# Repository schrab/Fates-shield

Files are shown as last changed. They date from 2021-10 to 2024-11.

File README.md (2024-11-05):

# Fates shield DAC board for Raspberry Pi

Monome [Fates](https://github.com/okyeron/fates) with MIDI and onboard microphone in Monome Shield form-factor

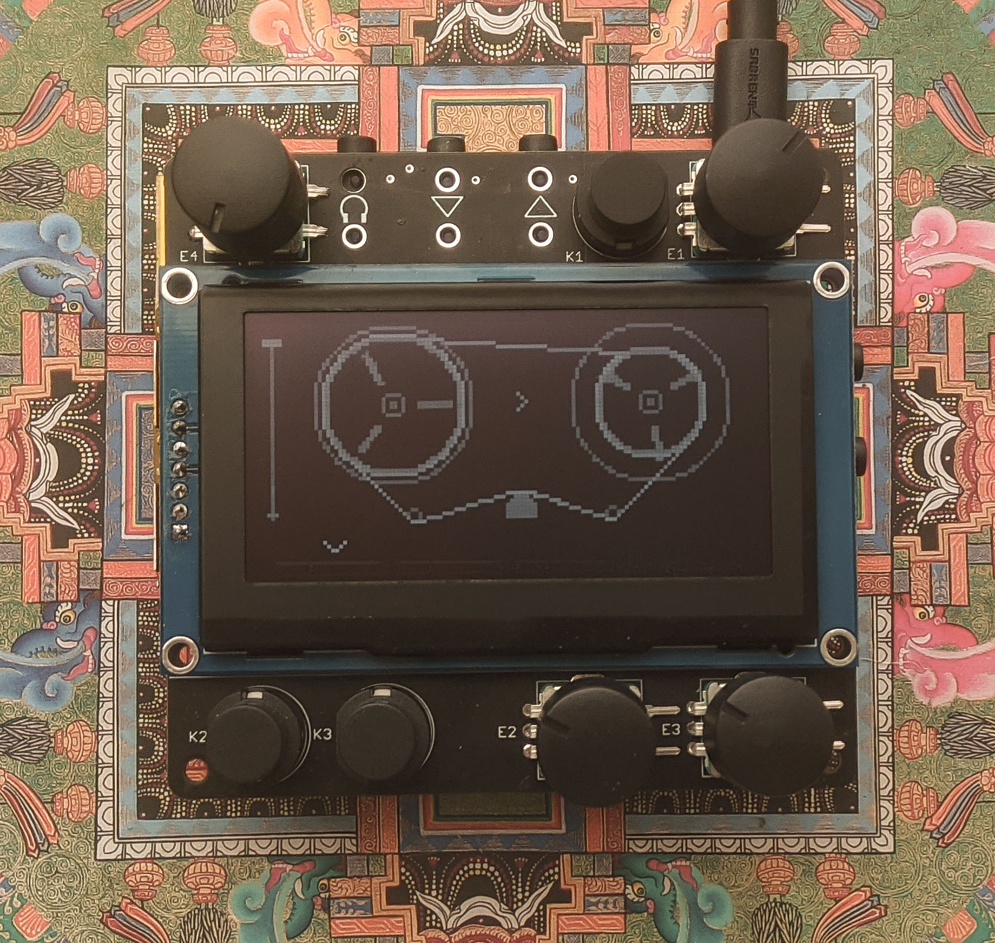
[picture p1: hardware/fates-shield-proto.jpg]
<fates shield>


### Specs:

- WM8731 stereo audio codec with headphone driver
- Microphone
- ZJYM270-7PV2.0 SSD1325 128x64 OLED display (NHD-2.7-12864WDW3 alternative [from Aliexpress](https://aliexpress.ru/item/4000265549668.html))
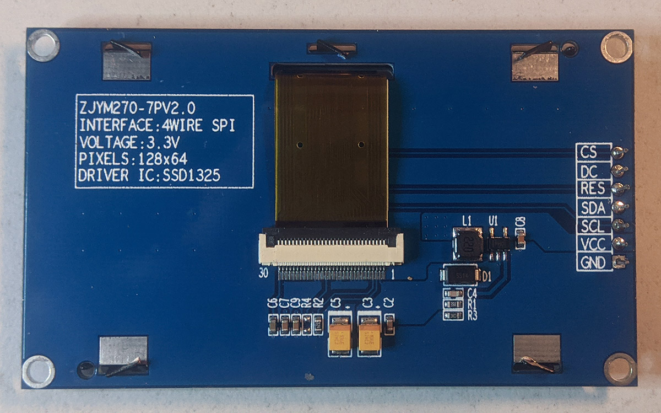
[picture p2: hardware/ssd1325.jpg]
<ssd1325oled>
  
- 3 pushbuttons
- 4 rotary encoders
- 2x 1/8in inputs
- 2x 1/8in outputs
- 1/8in stereo headphone out
- 1/8in UART MIDI in/out

###TODO
  
- [X] Fix upper OLED holes position
- [ ] Add RC filtering for encoders and keys
- [ ] Fix headphone jack hole
- [X] Fix swapped MIDI IN lines
- [X] Fix MIDI OUT buffer lines

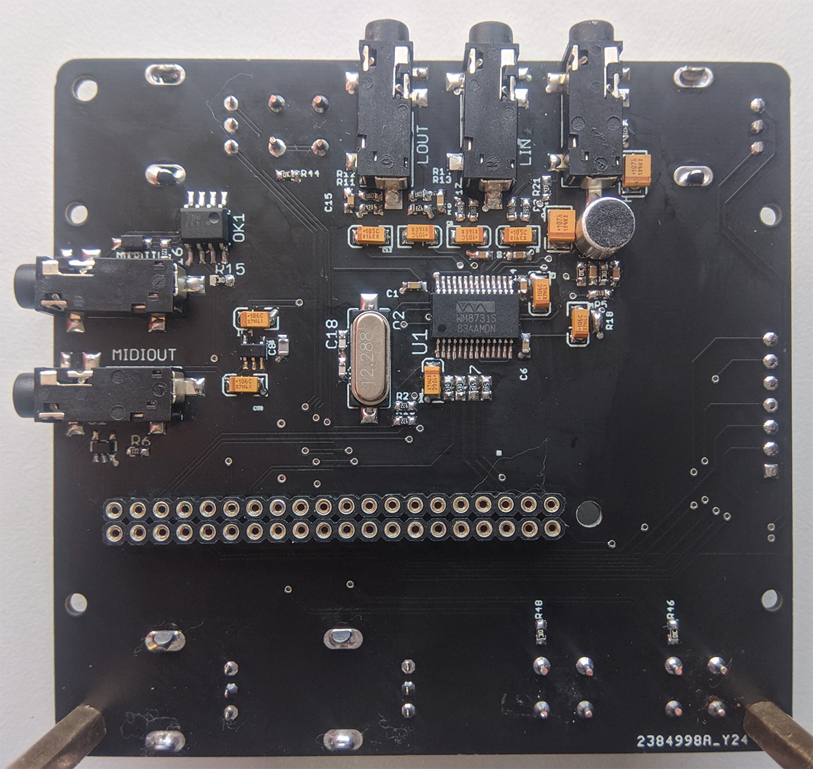
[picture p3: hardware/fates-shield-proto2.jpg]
<fates shield back>


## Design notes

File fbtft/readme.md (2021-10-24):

Dependencies
```sudo apt-get update
sudo apt-get dist-upgrade
sudo apt-get -y install libncurses5-dev
sudo apt-get install git bc raspberrypi-kernel-headers
```

Linux source

    git clone --depth=1 https://github.com/monome/linux
    cd ~/linux
    
Config

    cp /usr/src/linux-headers-$(uname -r)/Module.symvers .
    cp /usr/src/linux-headers-$(uname -r)/.config .

Copy **fb_ssd1325.c** to `~/linux/drivers/staging/fbtft`

Fix Kconfig and Makefile (SSD1305->SSD1325)

    make menuconfig

Select SSD1325

    Device Drivers  ---> Staging Drivers ---> Support for small TFT LCD display modules  --->
    <M>   SSD1325 driver

Compile

    make prepare
    make -j4 -C ~/linux SUBDIRS=drivers/staging/fbtft modules

Move drivers

    sudo cp -v ~/linux/drivers/staging/fbtft/*.ko /lib/modules/$(uname -r)/kernel/drivers/staging/fbtft/
    sudo modep -a

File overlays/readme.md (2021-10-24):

#SSD 1325 Device Tree overlay

SPI frequency set to 32MHz

Copy `fates-shield-ssd1325-overlay.dts` to `/home/we/fates/overlays/`

Compile dtb

    sudo dtc -W no-unit_address_vs_reg -@ -I dts -O dtb -o /boot/overlays/fates-ssd1325.dtbo /home/we/fates/overlays/fates-shield-ssd1325-overlay.dts

Edit `/boot/config.txt`

    # Screen
    dtoverlay=fates-ssd1325

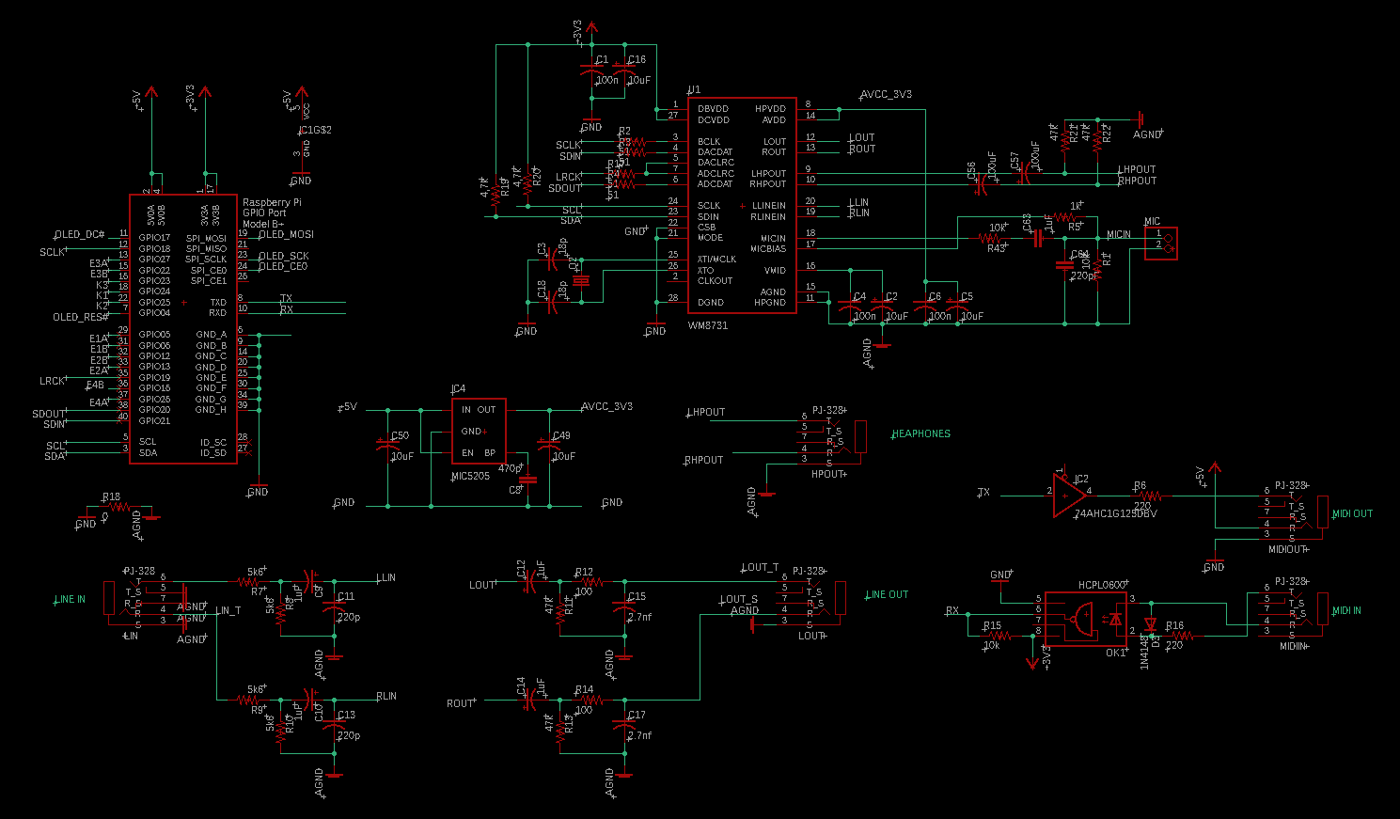
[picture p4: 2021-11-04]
hardware/fates-shield-schematic.png

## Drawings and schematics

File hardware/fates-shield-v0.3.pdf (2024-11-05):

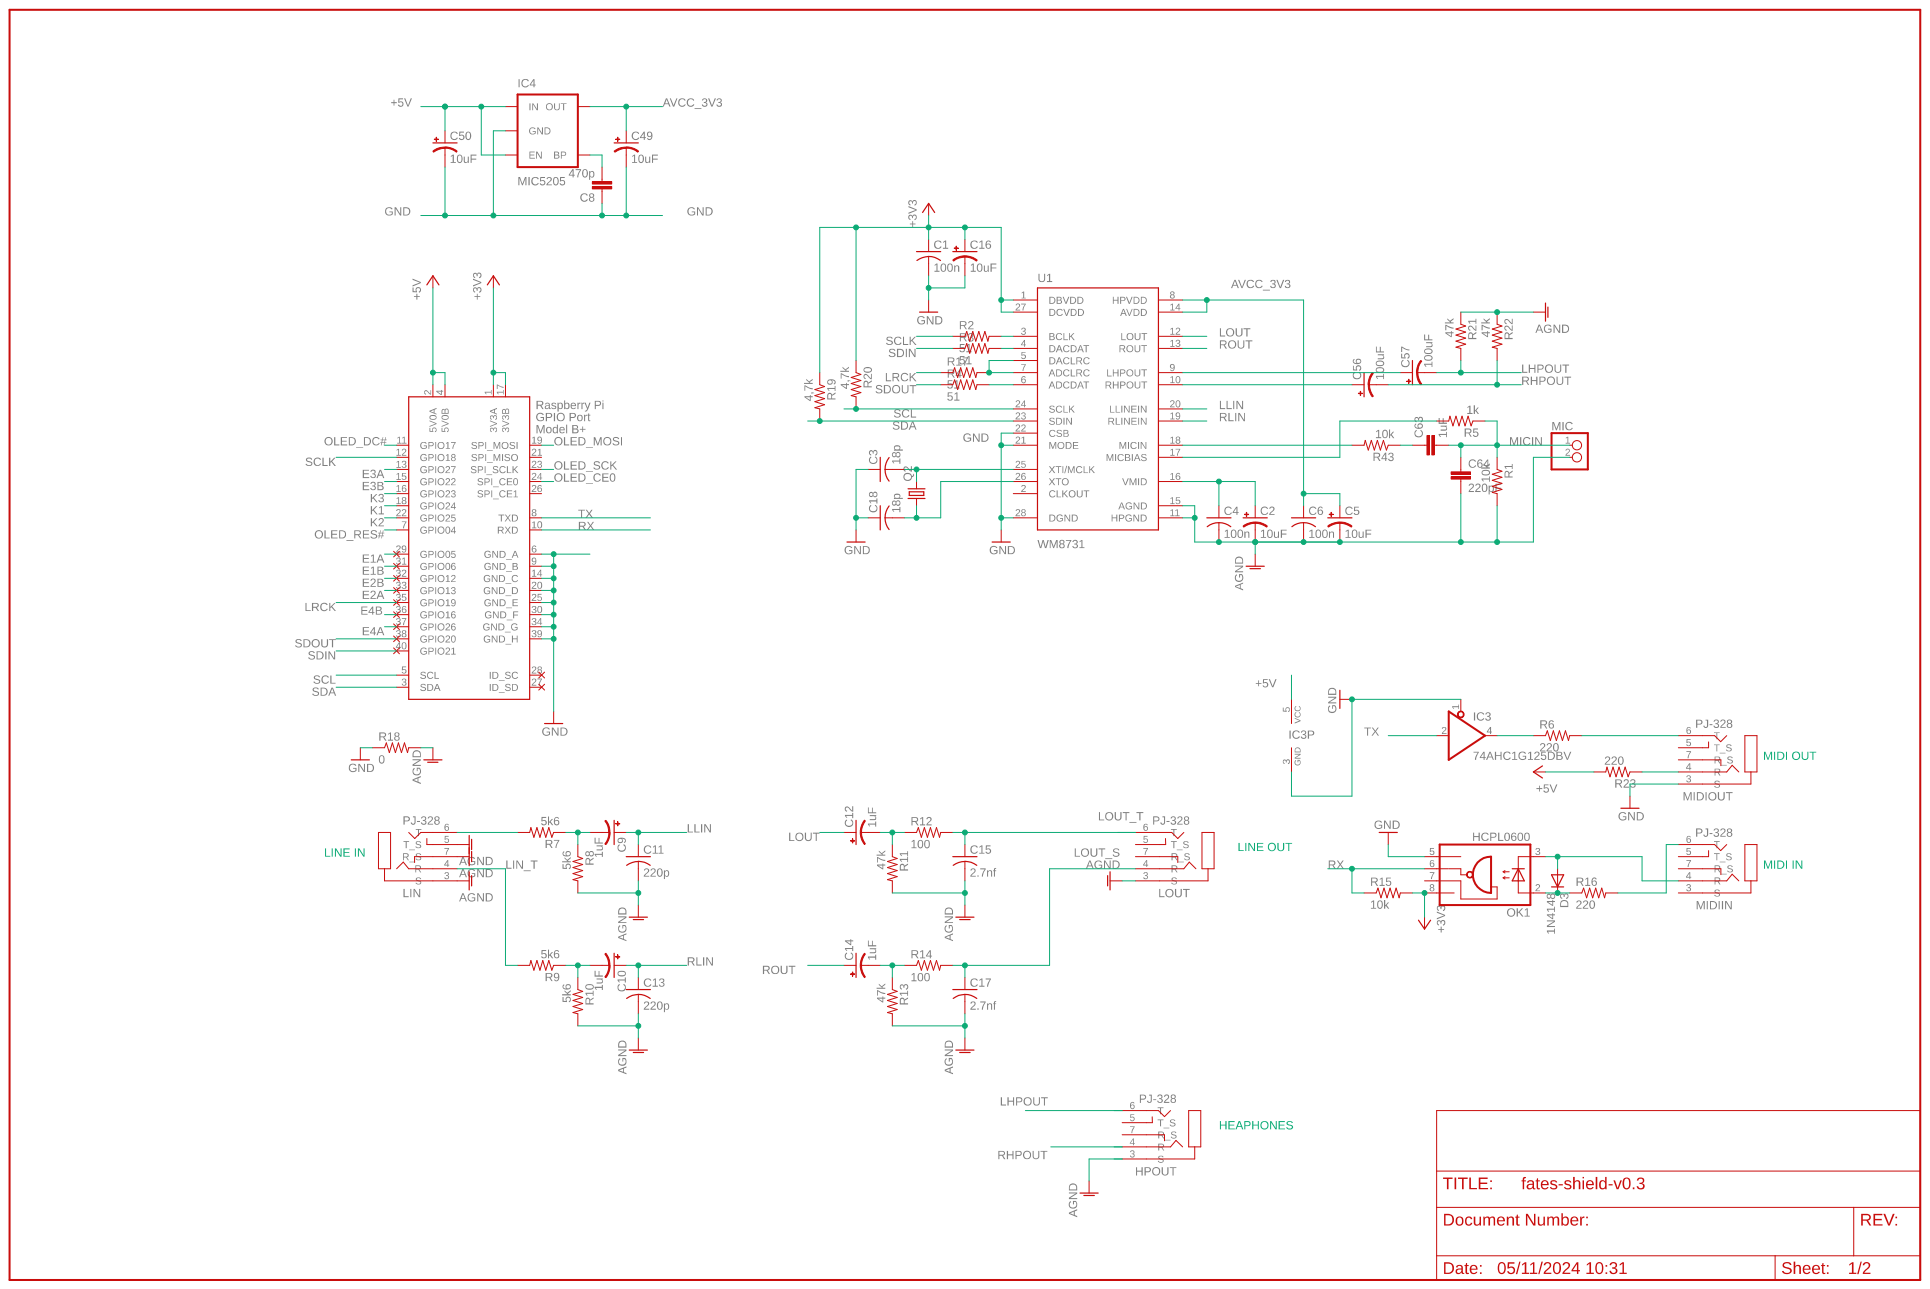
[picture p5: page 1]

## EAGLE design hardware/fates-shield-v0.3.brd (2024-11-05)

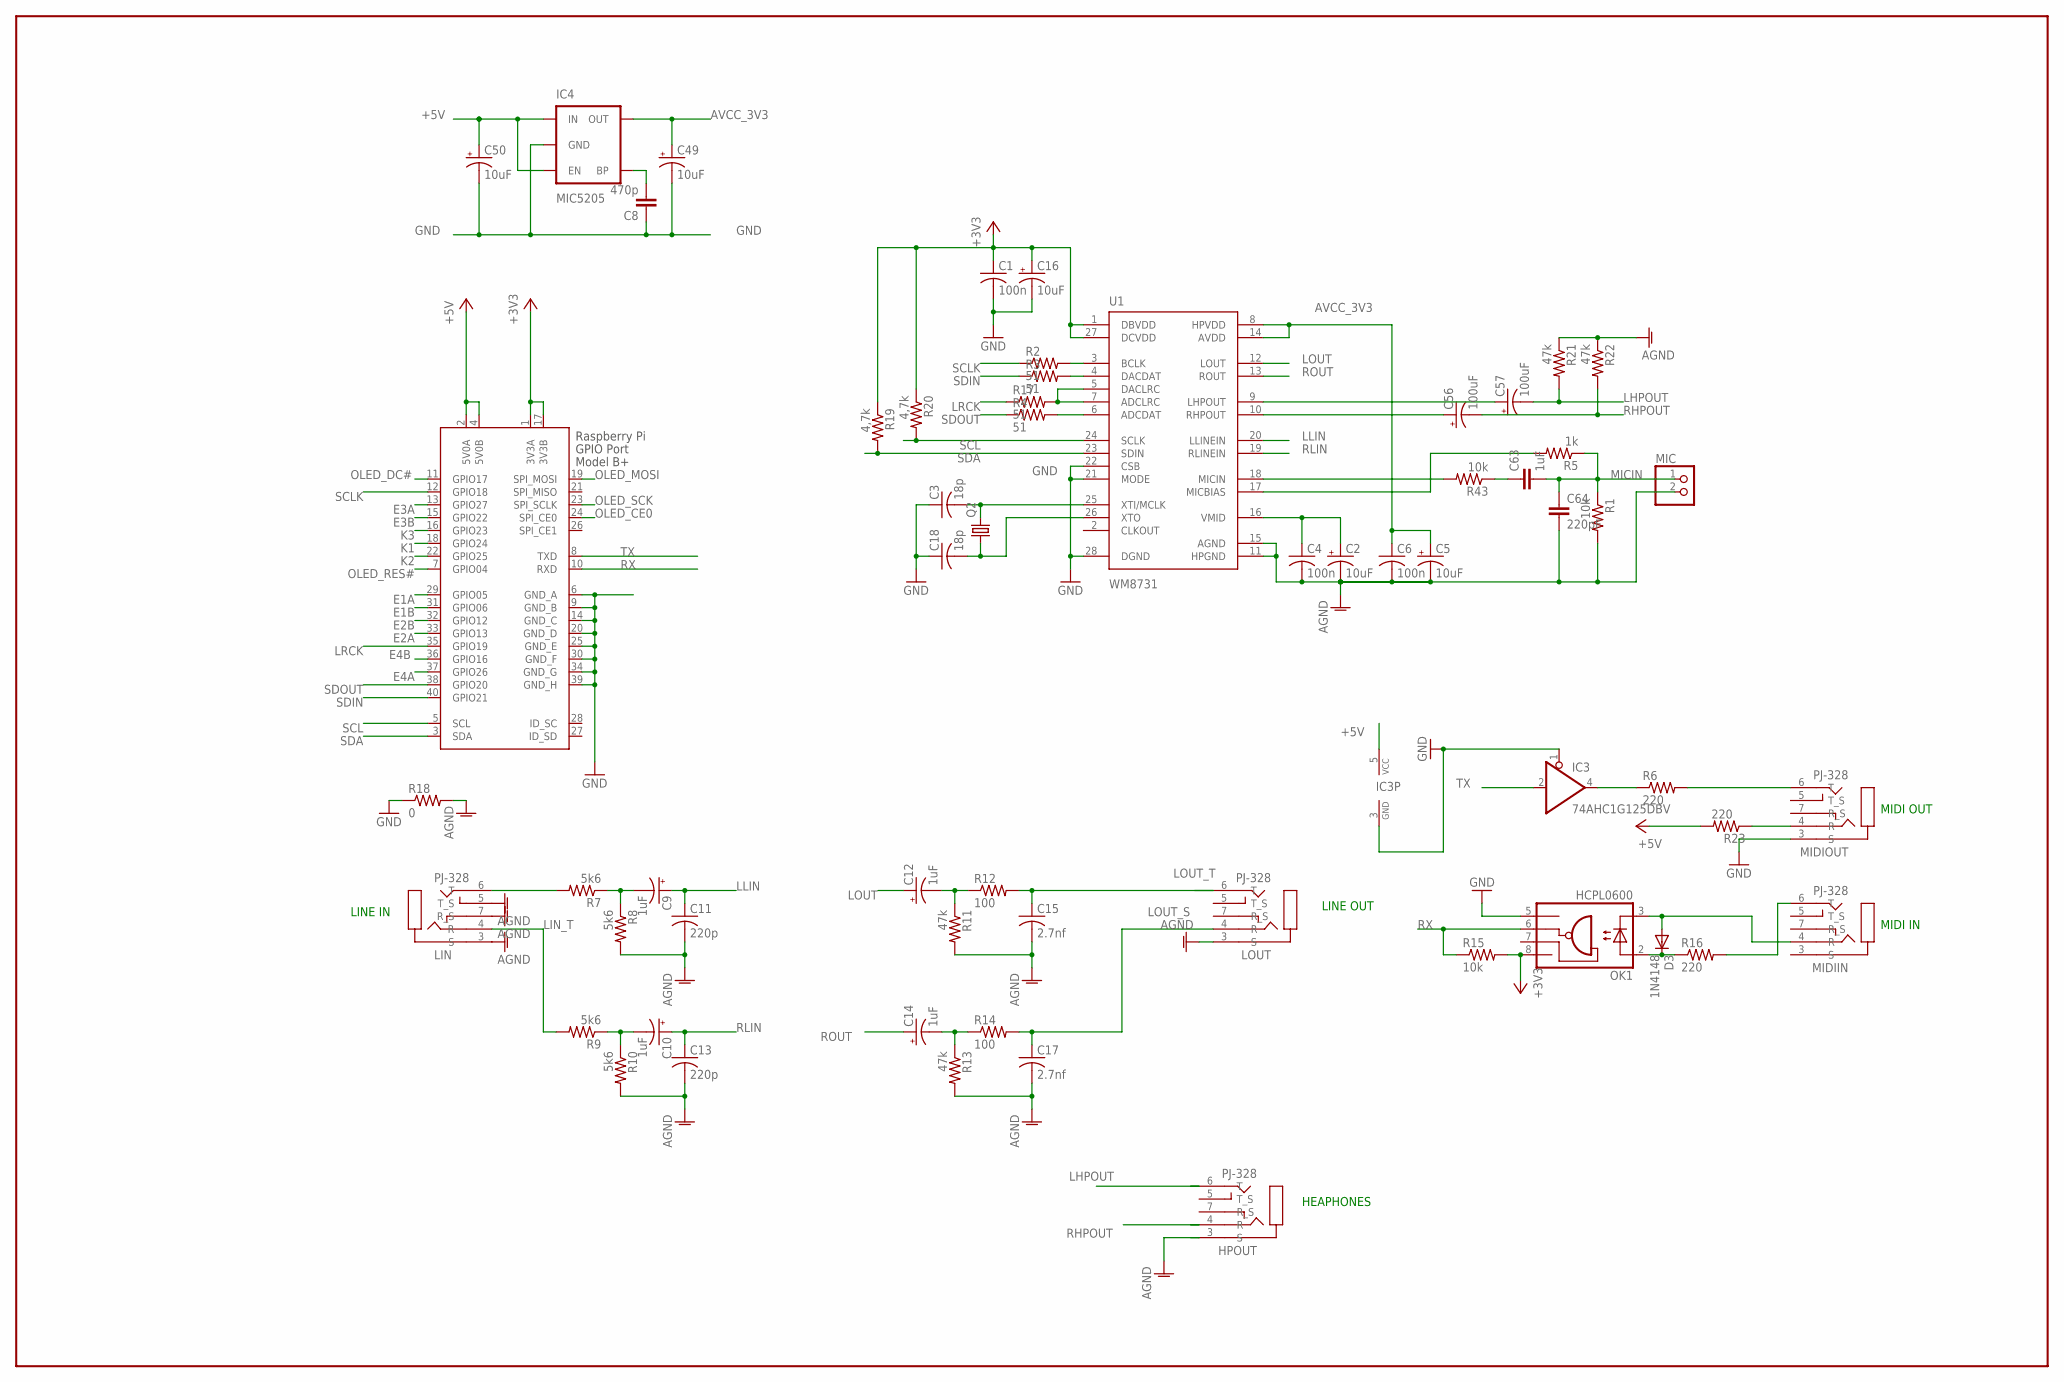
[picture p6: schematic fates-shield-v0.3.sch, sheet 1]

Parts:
C1, C4, C6: 100n; C0603
C2, C5, C16, C49, C50: 10uF; EIA3216
C3, C18: 18p; C0603
C8: 470p; 0603-CAP
C9, C10, C12, C14: 1uF; EIA3216
C11, C13: 220p; C0603
C15, C17: 2.7nf; C0603
C56, C57: 100uF; EIA3528
C63: 1uF; 0603-CAP
C64: 220pF; 0603-CAP
D3: 1N4148; SOD323-W
HPOUT: PJ-328; PJ328
IC3: 74AHC1G125DBV; DBV_R-PDSO-G5
IC4: MIC5205; SPARKFUN-3-2-07_SOT23-5
LIN: PJ-328; PJ328
LOUT: PJ-328; PJ328
MIC: PINHD-1X2; 1X02
MIDIIN: PJ-328; PJ328
MIDIOUT: PJ-328; PJ328
OK1: HCPL0600; SOIC08
Q2: CRYSTALHC49UP; HC49UP
R1, R43: 10k; 0603-RES
R2, R3, R4, R17: 51; R0603
R5: 1k; 0603-RES
R6, R16, R23: 220; R0603
R7, R8, R9, R10: 5k6; R0603
R11, R13: 47k; R0603
R12, R14: 100; R0603
R15: 10k; R0603
R18: 0; R0603
R19, R20: 4,7k; 0603-RES
R21, R22: 47k; 0603-RES
U1: WM8731; SSOP28
X1: RASPI_BOARD_B+#_E3; RASPI_BOARD_B+_EDGES_3DRILL

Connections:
+3V3: C1.1, C16.A (+), OK1.8 (VCC), R15.2, R19.1, R20.1, U1.1 (DBVDD), U1.27 (DCVDD), X1.1 (3V3A), X1.17 (3V3B); also elsewhere on the board
+5V: C50.A (+), IC3.5 (VCC), IC4.1 (IN), IC4.3 (EN), R23.2, X1.2 (5V0A), X1.4 (5V0B)
ADCDAT: R4.2, U1.6 (ADCDAT)
ADCLRC: R17.2, U1.5 (DACLRC), U1.7 (ADCLRC)
AGND: C2.C (-), C4.2, C5.C (-), C6.2, C11.2, C13.2, C15.2, C17.2, C64.2, HPOUT.3 (S), LIN.3 (S), LIN.5 (T_S), LIN.7 (R_S), LOUT.3 (S), MIC.2, R1.2, R8.2, R10.2, R11.2, R13.2, R18.2, R21.1, R22.1, U1.11 (HPGND), U1.15 (AGND)
AVCC_3V3: C5.A (+), C6.1, C49.A (+), IC4.5 (OUT), U1.8 (HPVDD), U1.14 (AVDD)
BCLK: R2.2, U1.3 (BCLK)
DACDAT: R3.2, U1.4 (DACDAT)
E1A: X1.29 (GPIO05); also elsewhere on the board
E1B: X1.31 (GPIO06); also elsewhere on the board
E2A: X1.33 (GPIO13); also elsewhere on the board
E2B: X1.32 (GPIO12); also elsewhere on the board
E3A: X1.13 (GPIO27); also elsewhere on the board
E3B: X1.15 (GPIO22); also elsewhere on the board
E4A: X1.37 (GPIO26); also elsewhere on the board
E4B: X1.36 (GPIO16); also elsewhere on the board
GND: C1.2, C3.1, C8.1, C16.C (-), C18.1, C49.C (-), C50.C (-), IC3.1 (OE), IC3.3 (GND), IC4.2 (GND), MIDIOUT.3 (S), OK1.5 (GND), R18.1, U1.21 (MODE), U1.22 (CSB), U1.28 (DGND), X1.6 (GND_A), X1.9 (GND_B), X1.14 (GND_C), X1.20 (GND_D), X1.25 (GND_E), X1.30 (GND_F), X1.34 (GND_G), X1.39 (GND_H); also elsewhere on the board
K1: X1.18 (GPIO24); also elsewhere on the board
K2: X1.22 (GPIO25); also elsewhere on the board
K3: X1.16 (GPIO23); also elsewhere on the board
LHPOUT: C57.C (-), HPOUT.6 (T), R21.2
LIN_T: LIN.4 (R), R9.2
LLIN: C9.A (+), C11.1, U1.20 (LLINEIN)
LOUT: C12.A (+), U1.12 (LOUT)
LOUT_S: C17.1, LOUT.4 (R), R14.2
LOUT_T: C15.1, LOUT.6 (T), R12.2
LRCK: R17.1, X1.35 (GPIO19)
L_HPOUT: C57.A (+), U1.9 (LHPOUT)
MICIN: C63.2, C64.1, MIC.1, R1.1, R5.1
MIC_BIAS: R5.2, U1.17 (MICBIAS)
MIC_IN: R43.2, U1.18 (MICIN)
unnamed: MIDIOUT.4 (R), R23.1
unnamed: IC3.4 (O), R6.1
unnamed: C2.A (+), C4.1, U1.16 (VMID)
unnamed: C9.C (-), R7.1, R8.1
unnamed: C10.C (-), R9.1, R10.1
unnamed: C14.C (-), R13.1, R14.1
unnamed: C12.C (-), R11.1, R12.1
unnamed: LIN.6 (T), R7.2
unnamed: D3.A, MIDIIN.4 (R), OK1.3 (C)
unnamed: D3.C, OK1.2 (A), R16.1
unnamed: MIDIIN.6 (T), R16.2
unnamed: MIDIOUT.6 (T), R6.2
unnamed: C8.2, IC4.4 (BP)
unnamed: C63.1, R43.1
OLED_CE0: X1.24 (SPI_CE0); also elsewhere on the board
OLED_DC#: X1.11 (GPIO17); also elsewhere on the board
OLED_MOSI: X1.19 (SPI_MOSI); also elsewhere on the board
OLED_RES#: X1.7 (GPIO04); also elsewhere on the board
OLED_SCK: X1.23 (SPI_SCLK); also elsewhere on the board
RHPOUT: C56.C (-), HPOUT.4 (R), R22.2
RLIN: C10.A (+), C13.1, U1.19 (RLINEIN)
ROUT: C14.A (+), U1.13 (ROUT)
RX: OK1.6 (VO), R15.1, X1.10 (RXD)
R_HPOUT: C56.A (+), U1.10 (RHPOUT)
SCL: R20.2, U1.24 (SCLK), X1.5 (SCL)
SCLK: R2.1, X1.12 (GPIO18)
SDA: R19.2, U1.23 (SDIN), X1.3 (SDA)
SDIN: R3.1, X1.40 (GPIO21)
SDOUT: R4.1, X1.38 (GPIO20)
TX: IC3.2 (I), X1.8 (TXD)
XTI: C3.2, Q2.2, U1.25 (XTI/MCLK)
XTO: C18.2, Q2.1, U1.26 (XTO)

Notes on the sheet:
MIDI OUT
MIDI IN
HEAPHONES
LINE OUT
LINE IN

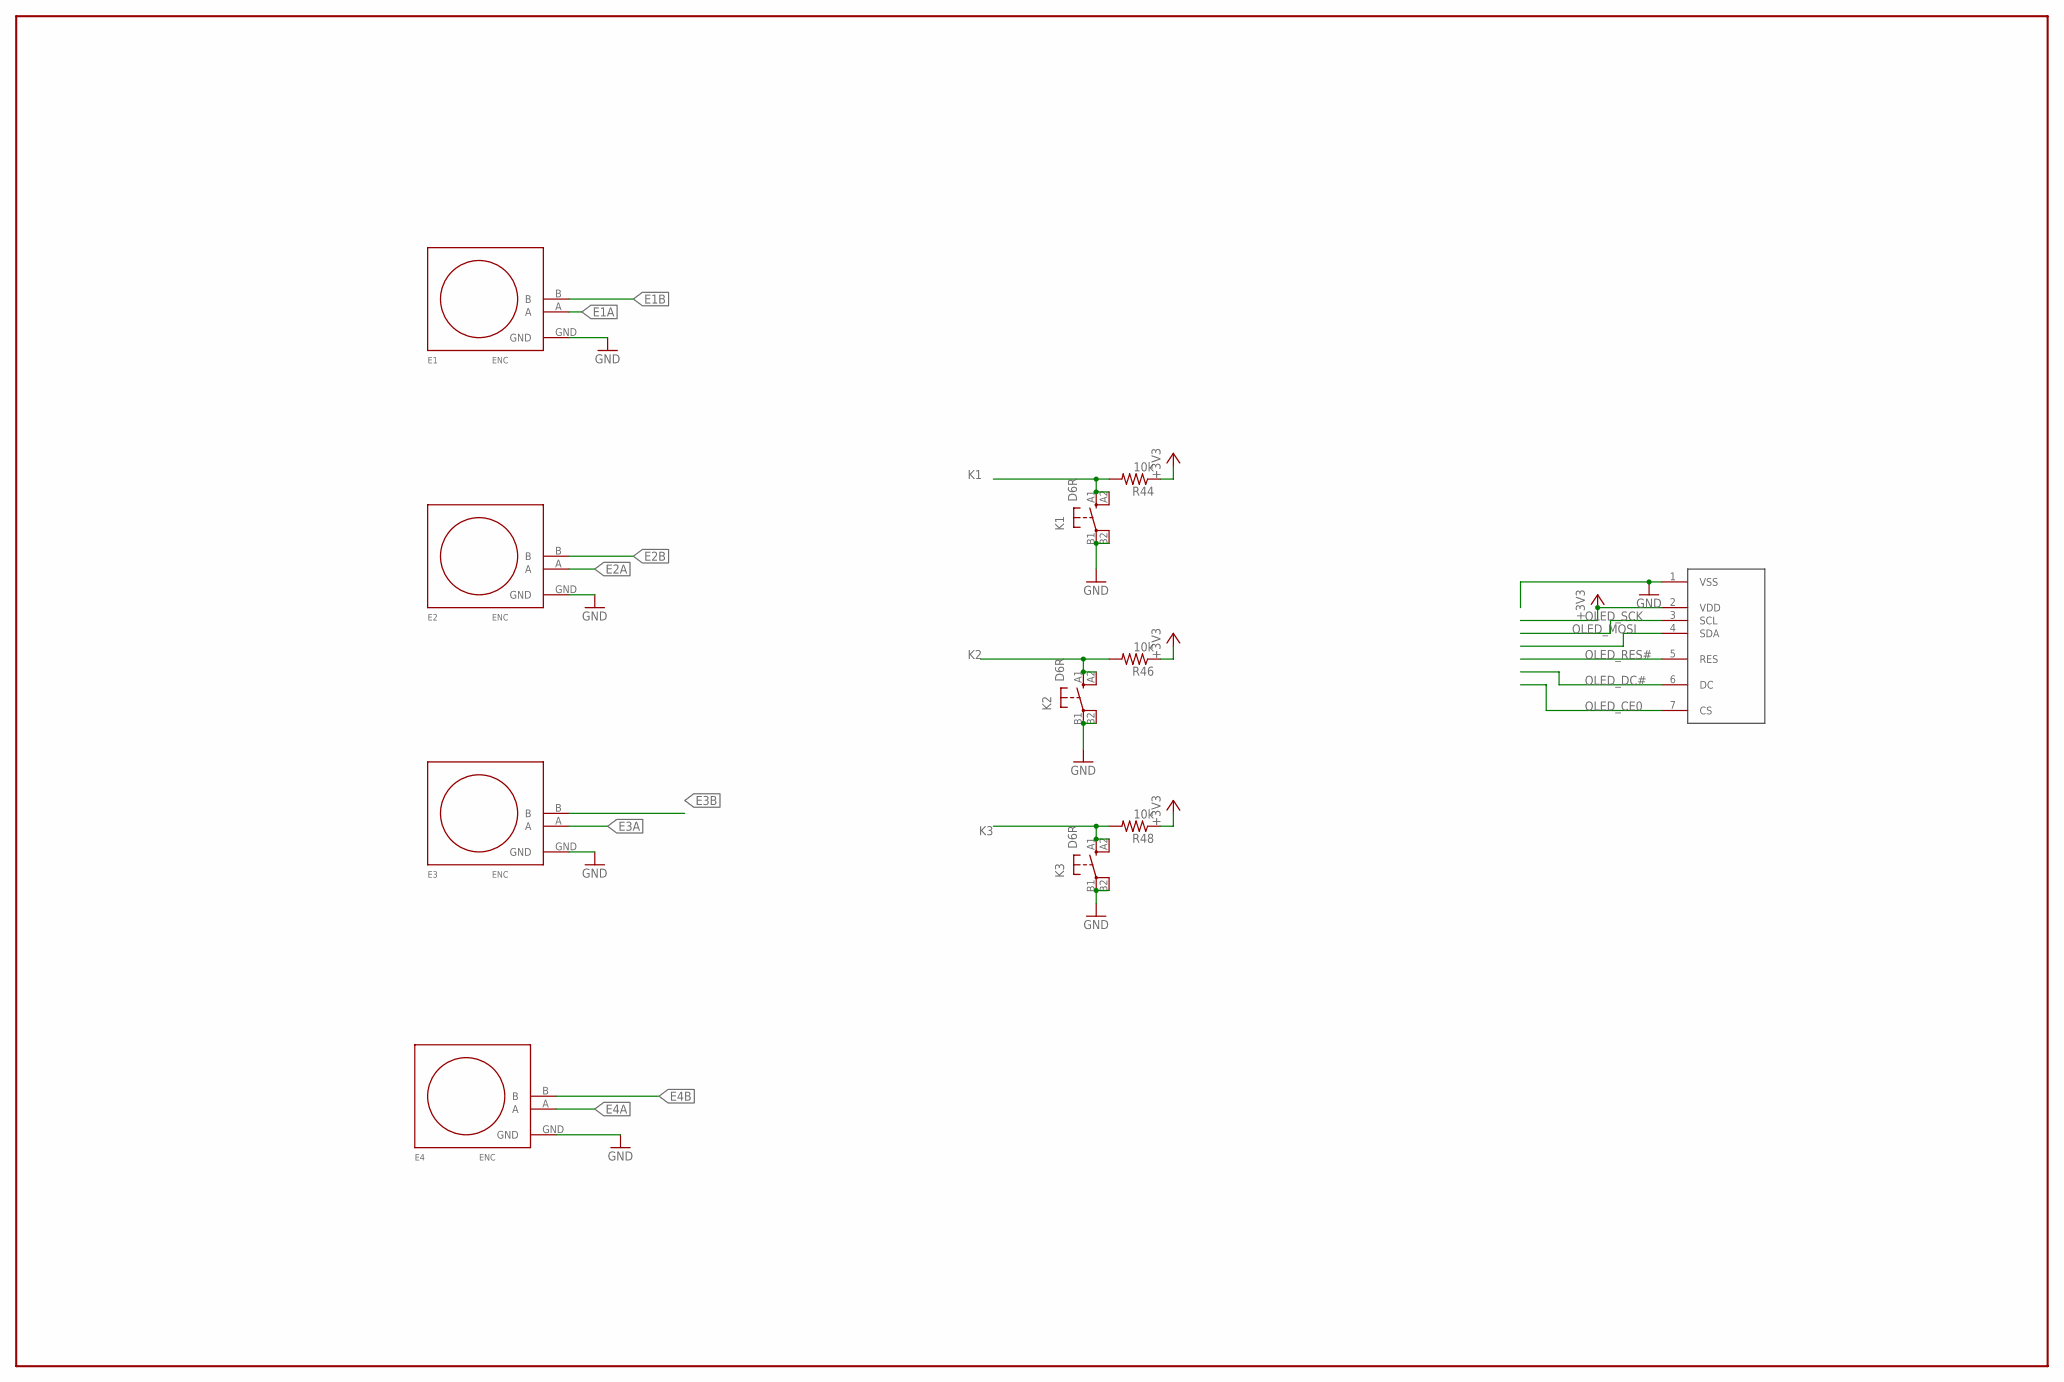
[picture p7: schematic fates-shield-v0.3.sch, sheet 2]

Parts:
E1, E2, E3, E4: ENC; PEC11RN
K1, K2, K3: D6R
R44, R46, R48: 10k; R0603
U$2: OLED128X64SSD1325; OLED-SSD1325

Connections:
+3V3: R44.1, R46.1, R48.1, U$2.2 (VDD); also elsewhere on the board
E1A: E1.A; also elsewhere on the board
E1B: E1.B; also elsewhere on the board
E2A: E2.A; also elsewhere on the board
E2B: E2.B; also elsewhere on the board
E3A: E3.A; also elsewhere on the board
E3B: E3.B; also elsewhere on the board
E4A: E4.A; also elsewhere on the board
E4B: E4.B; also elsewhere on the board
GND: E1.GND, E2.GND, E3.GND, E4.GND, K1.B1, K1.B2 (P1), K2.B1, K2.B2 (P1), K3.B1, K3.B2 (P1), U$2.1 (VSS); also elsewhere on the board
K1: K1.A1 (S), K1.A2 (S1), R44.2; also elsewhere on the board
K2: K2.A1 (S), K2.A2 (S1), R46.2; also elsewhere on the board
K3: K3.A1 (S), K3.A2 (S1), R48.2; also elsewhere on the board
OLED_CE0: U$2.7 (CS); also elsewhere on the board
OLED_DC#: U$2.6 (DC); also elsewhere on the board
OLED_MOSI: U$2.4 (SDA); also elsewhere on the board
OLED_RES#: U$2.5 (RES); also elsewhere on the board
OLED_SCK: U$2.3 (SCL); also elsewhere on the board

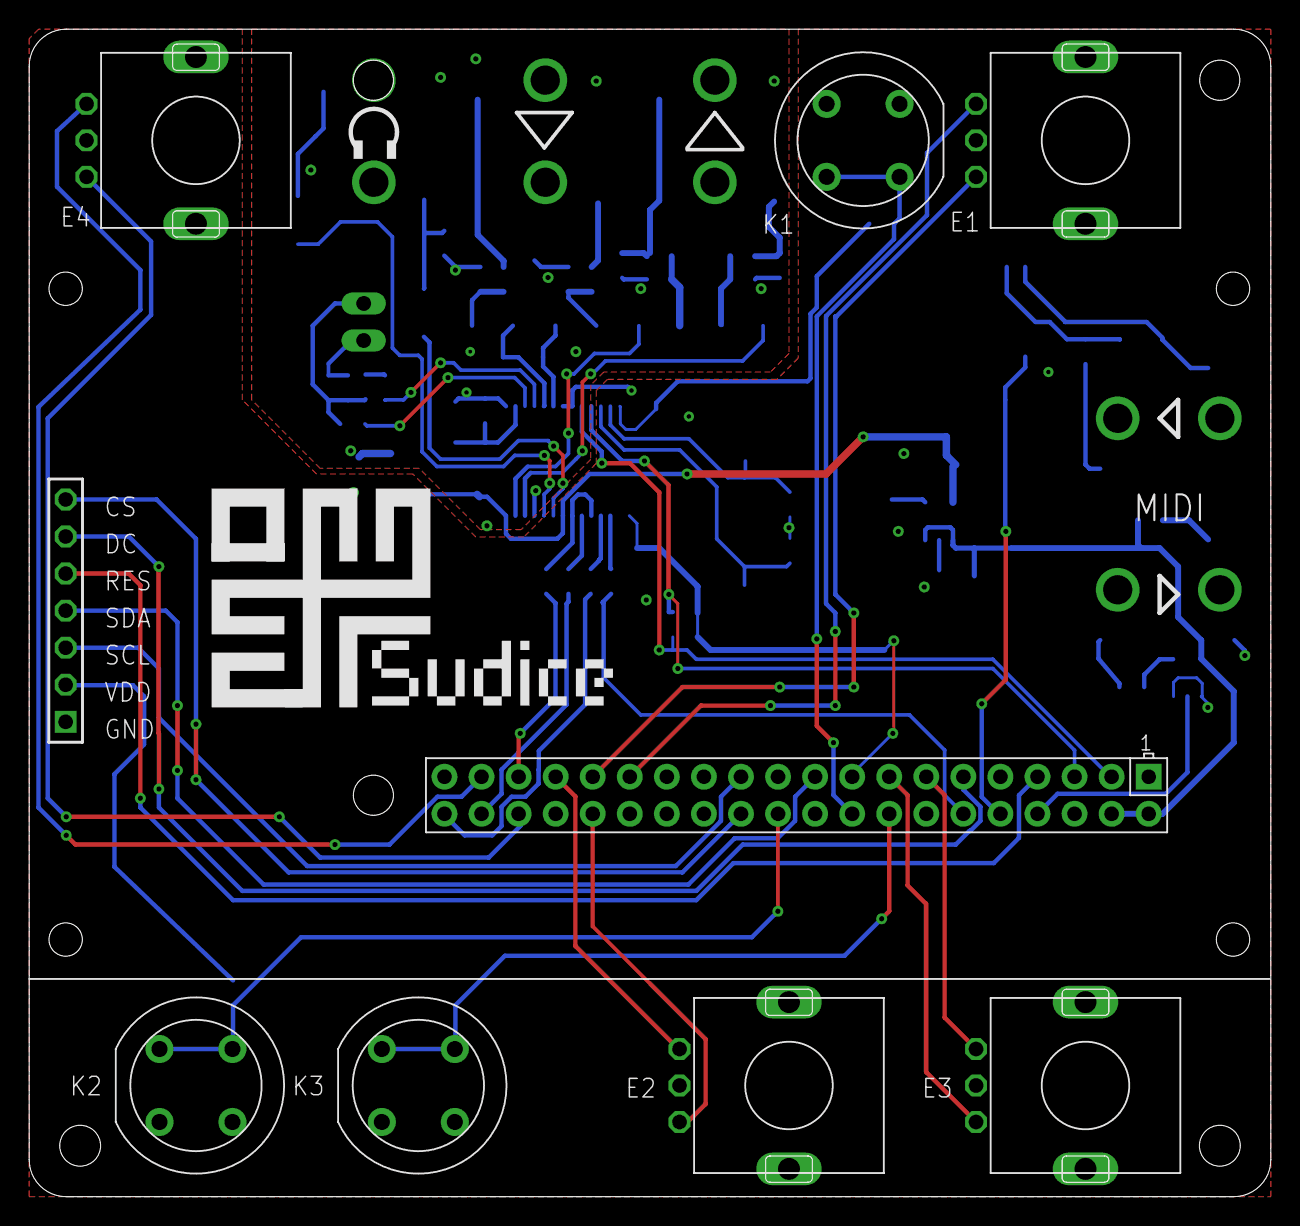
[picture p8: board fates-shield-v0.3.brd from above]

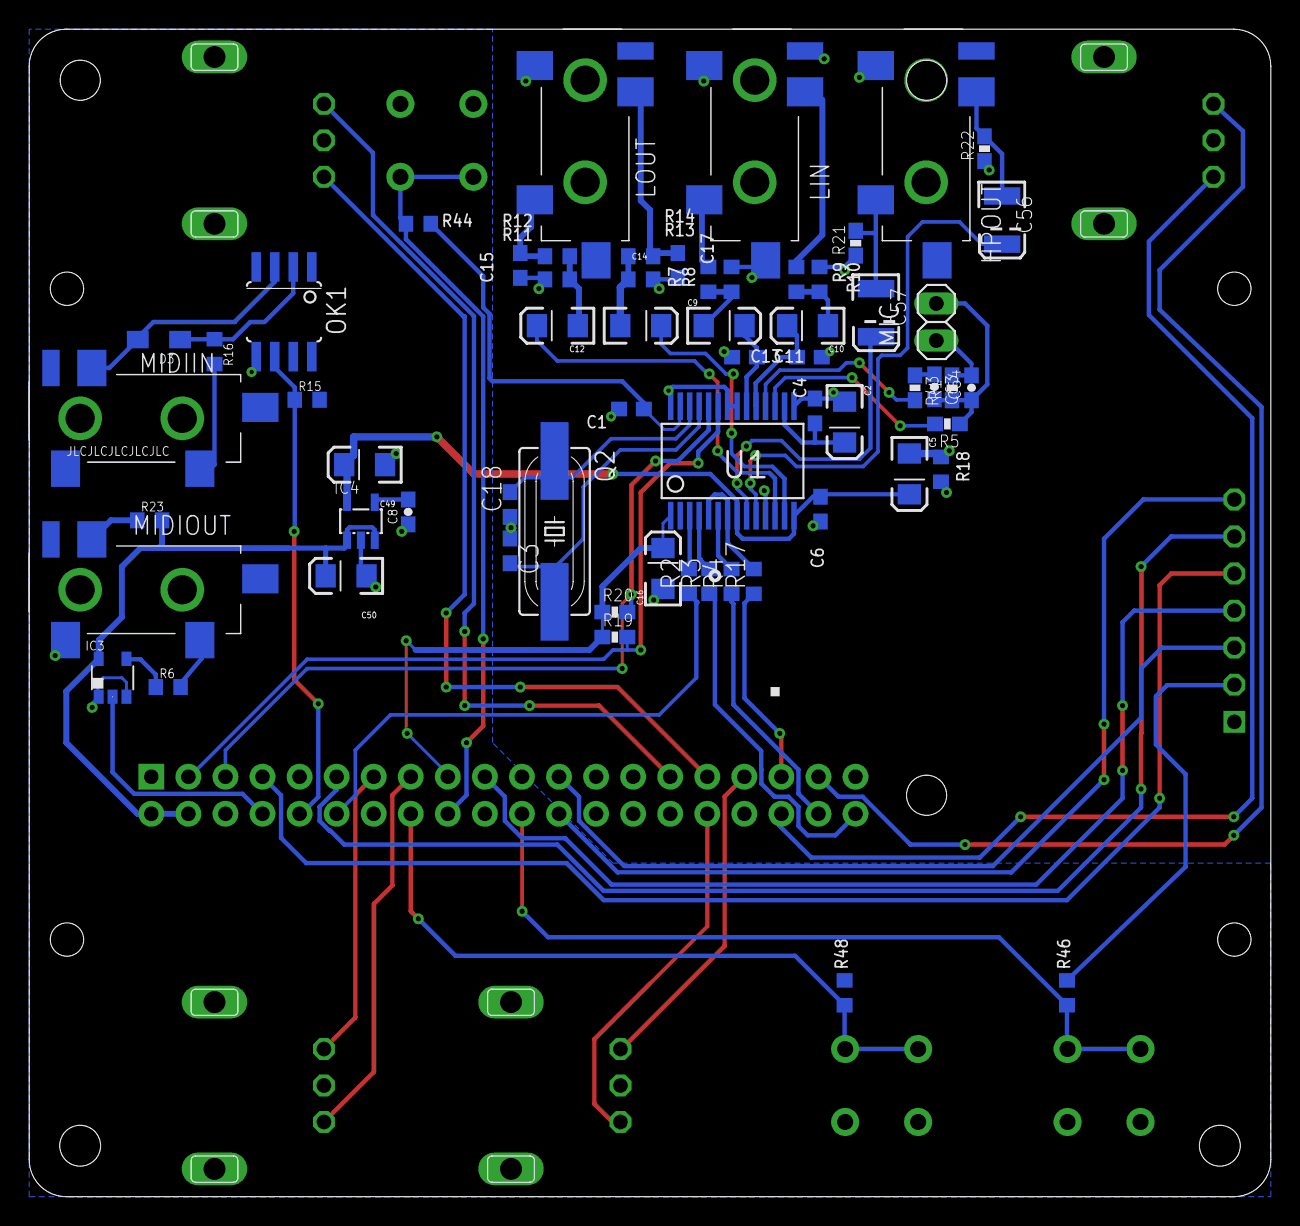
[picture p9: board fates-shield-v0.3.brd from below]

Board: 2 copper layers, 85.1 x 80.0 mm, 71 parts (62 on the bottom side), 63 nets.

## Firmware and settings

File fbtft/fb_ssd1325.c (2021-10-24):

// SPDX-License-Identifier: GPL-2.0+
/*
 * FB driver for the SSD1325 OLED Controller
 */

#include <linux/module.h>
#include <linux/kernel.h>
#include <linux/init.h>
#include <linux/gpio.h>
#include <linux/delay.h>
#include <linux/spi/spi.h>

#include "fbtft.h"

#define DRVNAME		"fb_ssd1325"

#define WIDTH 128
#define HEIGHT 64
#define GAMMA_NUM   1
#define GAMMA_LEN   15
#define DEFAULT_GAMMA "7 1 1 1 1 2 2 3 3 4 4 5 5 6 6"

/*
 * write_reg() caveat:
 *
 *    This doesn't work because D/C has to be LOW for both values:
 *      write_reg(par, val1, val2);
 *
 *    Do it like this:
 *      write_reg(par, val1);
 *      write_reg(par, val2);
 */

/* Init sequence taken from the Adafruit SSD1306 Arduino library */
static int init_display(struct fbtft_par *par)
{
	par->fbtftops.reset(par);

	gpio_set_value(par->gpio.cs, 0);
	/* Turn the display off. */
	write_reg(par, 0xAE);
	/* Set the oscillator division. */
	write_reg(par, 0xb3);
	write_reg(par, 0xF1);
	/* Set the multiplex ratio to 1/64 duty cycle. */
	write_reg(par, 0xa8);
	write_reg(par, 0x3f);
	/* Set the display offset (fixed) */
	write_reg(par, 0xA2);
	write_reg(par, 0x4C);
	/* Set the start line to 0. */
	write_reg(par, 0xa1);
	write_reg(par, 0x00);
	/* Set Master Config to DC/DC Converter. */
	write_reg(par, 0xAD);
	write_reg(par, 0x02);
	/* Set segment remap to 0x50: */
	/* 1010000 (COM split, remap bottom-up, horiz. increment, no nibble remap).*/
	write_reg(par, 0xa0);
	write_reg(par, 0x56); // 56 - 180 - 45/50 normal
	/* Set full current range. */
	write_reg(par, 0x86);
	/* Set the gray color palette. */
	/* 0x01, 0x11, 0x22, 0x32, 0x43, 0x54, 0x65, 0x76 */
	write_reg(par, 0x01);
	write_reg(par, 0x11);
	write_reg(par, 0x22);
	write_reg(par, 0x32);
	write_reg(par, 0x43);
	write_reg(par, 0x54);
	write_reg(par, 0x65);
	write_reg(par, 0x76);
	/* Set the contrast to maximum. */
	write_reg(par, 0x81);
	write_reg(par, 0x7f);
	/* Set the row period. */
	write_reg(par, 0xB2);
	write_reg(par, 0x51);
	/* Set the phase length. */
	write_reg(par, 0xB1);
	write_reg(par, 0x55);
	/* Set the precharge comparator to 2. */
	write_reg(par, 0xB4);
	write_reg(par, 0x02);
	/* Enable the precharge comparator. */
	write_reg(par, 0xB0);
	write_reg(par, 0x28);
	/* Set the high voltage level of the COM pin (0x1C = 0.80 * Vref). */
	write_reg(par, 0xBE);
	write_reg(par, 0x55);
	/* Set the low voltage level of the SEG pin. Value may be wrong. */
	write_reg(par, 0xBF);
	write_reg(par, 0x02);
	/* Set the display to non-inverted configuration. */
	write_reg(par, 0xA4);
	/* turn Display on */
	write_reg(par, 0xAF);
	return 0;
}

static uint8_t rgb565_to_g16(u16 pixel)
{
	u16 b = pixel & 0x1f;
	u16 g = (pixel & (0x3f << 5)) >> 5;
	u16 r = (pixel & (0x1f << (5 + 6))) >> (5 + 6);

	pixel = (299 * r + 587 * g + 114 * b) / 195;
	if (pixel > 255)
		pixel = 255;
	return (uint8_t)pixel / 16;
}

static void set_addr_win(struct fbtft_par *par, int xs, int ys, int xe, int ye)
{
	fbtft_par_dbg(DEBUG_SET_ADDR_WIN, par,
		      "%s(xs=%d, ys=%d, xe=%d, ye=%d)\n", __func__, xs, ys, xe,
		      ye);

	write_reg(par, 0x75);
	write_reg(par, 0x00);
	write_reg(par, 0x3f);
	write_reg(par, 0x15);
	write_reg(par, 0x00);
	write_reg(par, 0x7f);
}

static int blank(struct fbtft_par *par, bool on)
{
	fbtft_par_dbg(DEBUG_BLANK, par, "(%s=%s)\n",
		      __func__, on ? "true" : "false");

	if (on)
		write_reg(par, 0xAE);
	else
		write_reg(par, 0xAF);
	return 0;
}

/*
 * Grayscale Lookup Table
 * GS1 - GS15
 * The "Gamma curve" contains the relative values between the entries
 * in the Lookup table.
 *
 * 0 = Setting of GS1 < Setting of GS2 < Setting of GS3.....<
 * Setting of GS14 < Setting of GS15
 */
static int set_gamma(struct fbtft_par *par, u32 *curves)
{
	int i;

	fbtft_par_dbg(DEBUG_INIT_DISPLAY, par, "%s()\n", __func__);

	for (i = 0; i < GAMMA_LEN; i++) {
		if (i > 0 && curves[i] < 1) {
			dev_err(par->info->device,
				"Illegal value in Grayscale Lookup Table at index %d.\n"
				"Must be greater than 0\n", i);
			return -EINVAL;
		}
		if (curves[i] > 7) {
			dev_err(par->info->device,
				"Illegal value(s) in Grayscale Lookup Table.\n"
				"At index=%d, the accumulated value has exceeded 7\n",
				i);
			return -EINVAL;
		}
	}
	write_reg(par, 0xB8);
	for (i = 0; i < 8; i++)
		write_reg(par, (curves[i] & 0xFF));
	return 0;
}

static int write_vmem(struct fbtft_par *par, size_t offset, size_t len)
{
	u16 *vmem16 = (u16 *)par->info->screen_buffer;
	u8 *buf = par->txbuf.buf;
	u8 n1;
	u8 n2;
	int y, x;
	int ret;

	for (x = 0; x < par->info->var.xres; x++) {
		if (x % 2)
			continue;
		for (y = 0; y < par->info->var.yres; y++) {
			n1 = rgb565_to_g16(vmem16[y * par->info->var.xres + x]);
			n2 = rgb565_to_g16(vmem16
					   [y * par->info->var.xres + x + 1]);
			*buf = (n1 << 4) | n2;
			buf++;
		}
	}

	gpio_set_value(par->gpio.dc, 1);

	/* Write data */
	ret = par->fbtftops.write(par, par->txbuf.buf,
				par->info->var.xres * par->info->var.yres / 2);
	if (ret < 0)
		dev_err(par->info->device,
			"%s: write failed and returned: %d\n", __func__, ret);

	return ret;
}

static struct fbtft_display display = {
	.regwidth = 8,
	.width = WIDTH,
	.height = HEIGHT,
	.txbuflen = WIDTH * HEIGHT / 2,
	.gamma_num = GAMMA_NUM,
	.gamma_len = GAMMA_LEN,
	.gamma = DEFAULT_GAMMA,
	.fbtftops = {
		.write_vmem = write_vmem,
		.init_display = init_display,
		.set_addr_win = set_addr_win,
		.blank = blank,
		.set_gamma = set_gamma,
	},
};

FBTFT_REGISTER_DRIVER(DRVNAME, "solomon,ssd1325", &display);

MODULE_ALIAS("spi:" DRVNAME);
MODULE_ALIAS("platform:" DRVNAME);
MODULE_ALIAS("spi:ssd1325");
MODULE_ALIAS("platform:ssd1325");

MODULE_DESCRIPTION("SSD1325 OLED Driver");
MODULE_AUTHOR("Alexander Tugov");
MODULE_LICENSE("GPL");
